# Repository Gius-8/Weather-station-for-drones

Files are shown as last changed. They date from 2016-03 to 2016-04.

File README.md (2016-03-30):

## Weather station for drones
The project consists of a kit for drones that includes an electronic device that functions as a meteorological station used for monitoring the values of environmental temperature, of atmospheric pressure and of humidity. The whole device'll work thanks to Arduino/Genuino MKR1000.
The electronic device will have inside a GPS locator so as to know the exact position of the analog readings of the different sensors.
The values acquired will be preserved in a KML files on a microSD and you can view them with Google Earth or Google Maps by simply importing the KML file.
They can be monitored in real time via Wi-Fi hotspot using a Smatphone, Tablet or PC.
In addition to the meteorological data, the device can acquire altitude, geographical coordinates and the speed of the drone in m/s.
The device consumes little power and can be powered by a 3.7V LiPo thanks to the potential of mkr1000 board.
In summary, the device will have the following characteristics:
You will be able to acquire:

- Temperature
- Atmospheric pressure
- Humidity
- Speed
- Altitude drone
- Geographic coordinates

Link tutorial: https://www.hackster.io/gius_8/weather-station-for-drones-1184cd

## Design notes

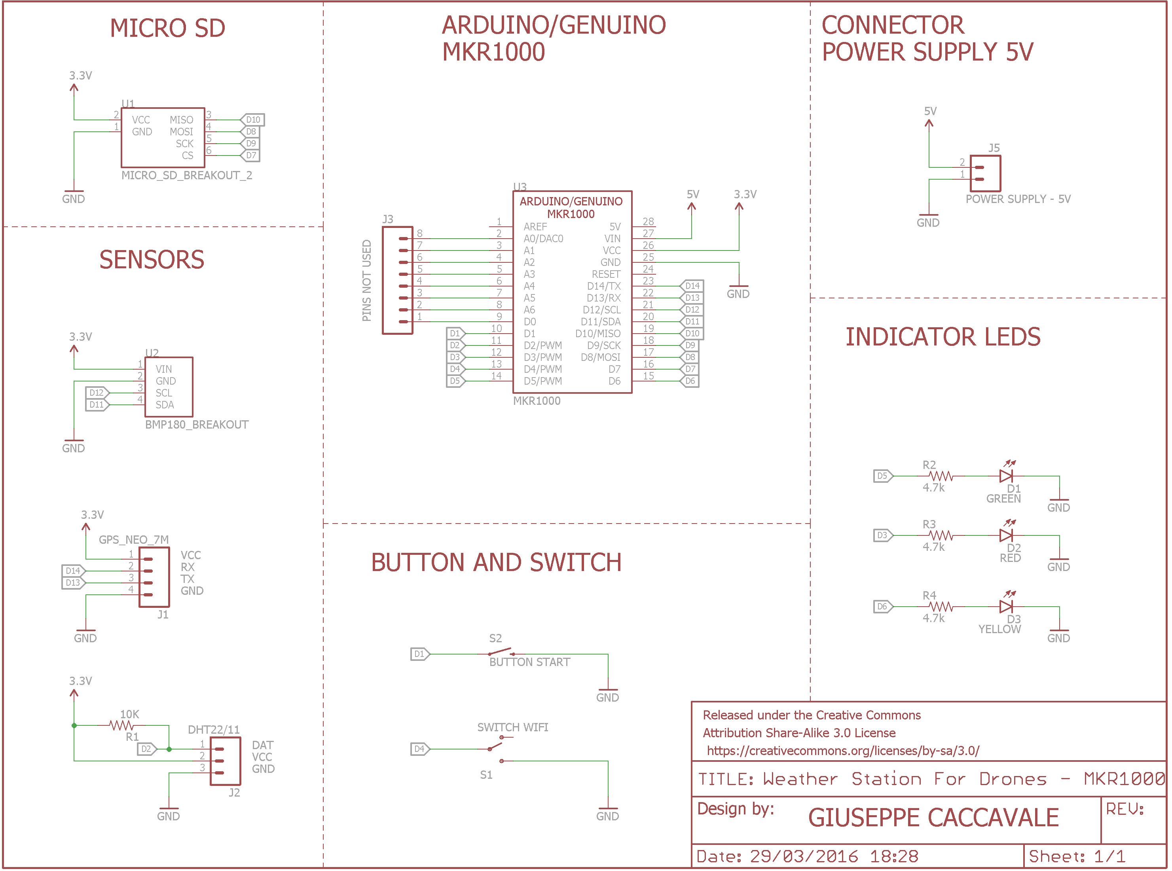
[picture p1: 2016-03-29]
Schematic_Weather_Station.png

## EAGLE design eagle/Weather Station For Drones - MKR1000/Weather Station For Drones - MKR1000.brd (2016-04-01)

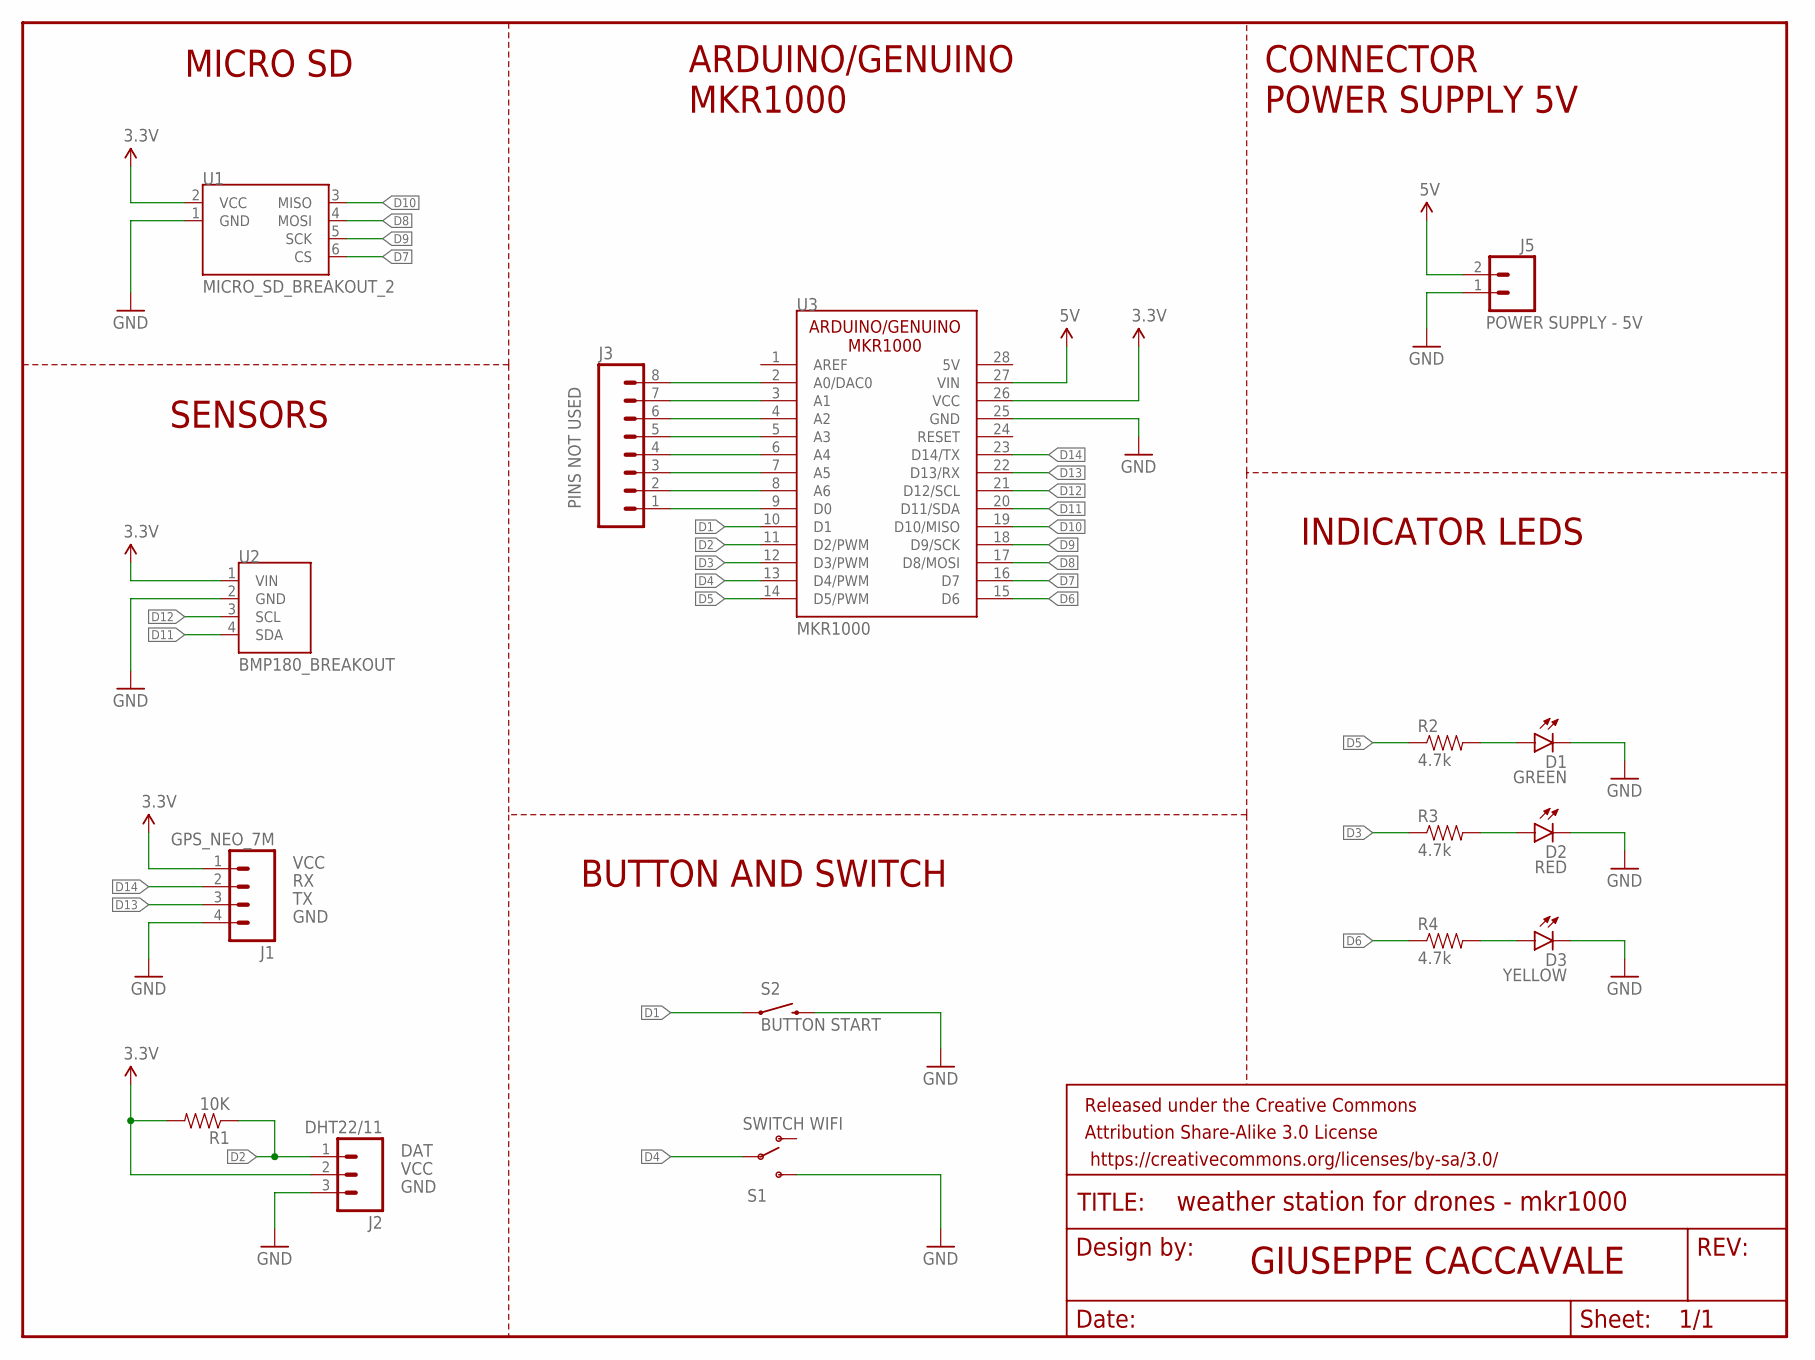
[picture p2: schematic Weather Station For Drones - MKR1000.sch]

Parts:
D1: GREEN; LED3MM
D2: RED; LED3MM
D3: YELLOW; LED3MM
FRAME1: FRAME-LETTER; CREATIVE_COMMONS
J1: GPS_NEO_7M; 1X04_LONGPADS
J2: DHT22/11; 1X03_LONGPADS
J3: PINS NOT USED; 1X08_LONGPADS
J5: POWER SUPPLY - 5V; JST-2-PTH
R1: 10K; AXIAL-0.3
R2, R3, R4: 4.7k; AXIAL-0.3
S1: SWITCH WIFI; SWITCH-SPDT_KIT
S2: BUTTON START; TACTILE-PTH
U1: MICRO_SD_BREAKOUT_2; MICRO_SD_ONLY_PIN
U2: BMP180_BREAKOUT
U3: MKR1000

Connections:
3.3V: J1.1, J2.2, R1.P$2 (2), U1.2 (VCC), U2.1 (VIN), U3.26 (VCC)
5V: J5.2, U3.27 (VIN)
D1: S2.1, S2.2 (1), U3.10 (D1)
D2: J2.1, R1.P$1 (1), U3.11 (D2/PWM)
D3: R3.P$1 (1), U3.12 (D3/PWM)
D4: S1.2, U3.13 (D4/PWM)
D5: R2.P$1 (1), U3.14 (D5/PWM)
D6: R4.P$1 (1), U3.15 (D6)
D7: U1.6 (CS), U3.16 (D7)
D8: U1.4 (MOSI), U3.17 (D8/MOSI)
D9: U1.5 (SCK), U3.18 (D9/SCK)
D10: U1.3 (MISO), U3.19 (D10/MISO)
D11: U2.4 (SDA), U3.20 (D11/SDA)
D12: U2.3 (SCL), U3.21 (D12/SCL)
D13: J1.3, U3.22 (D13/RX)
D14: J1.2, U3.23 (D14/TX)
GND: D1.K (C), D2.K (C), D3.K (C), J1.4, J2.3, J5.1, S1.3 (S), S2.3 (2), S2.4 (2), U1.1 (GND), U2.2 (GND), U3.25 (GND)
unnamed: D1.A, R2.P$2 (2)
unnamed: D2.A, R3.P$2 (2)
unnamed: J3.1, U3.9 (D0)
unnamed: J3.2, U3.8 (A6)
unnamed: J3.3, U3.7 (A5)
unnamed: J3.4, U3.6 (A4)
unnamed: J3.5, U3.5 (A3)
unnamed: J3.6, U3.4 (A2)
unnamed: J3.7, U3.3 (A1)
unnamed: J3.8, U3.2 (A0/DAC0)
unnamed: D3.A, R4.P$2 (2)

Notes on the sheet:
GND
VCC
DAT
GIUSEPPE CACCAVALE
SENSORS
CONNECTOR POWER SUPPLY 5V
INDICATOR LEDS
BUTTON AND SWITCH
ARDUINO/GENUINO MKR1000
MICRO SD

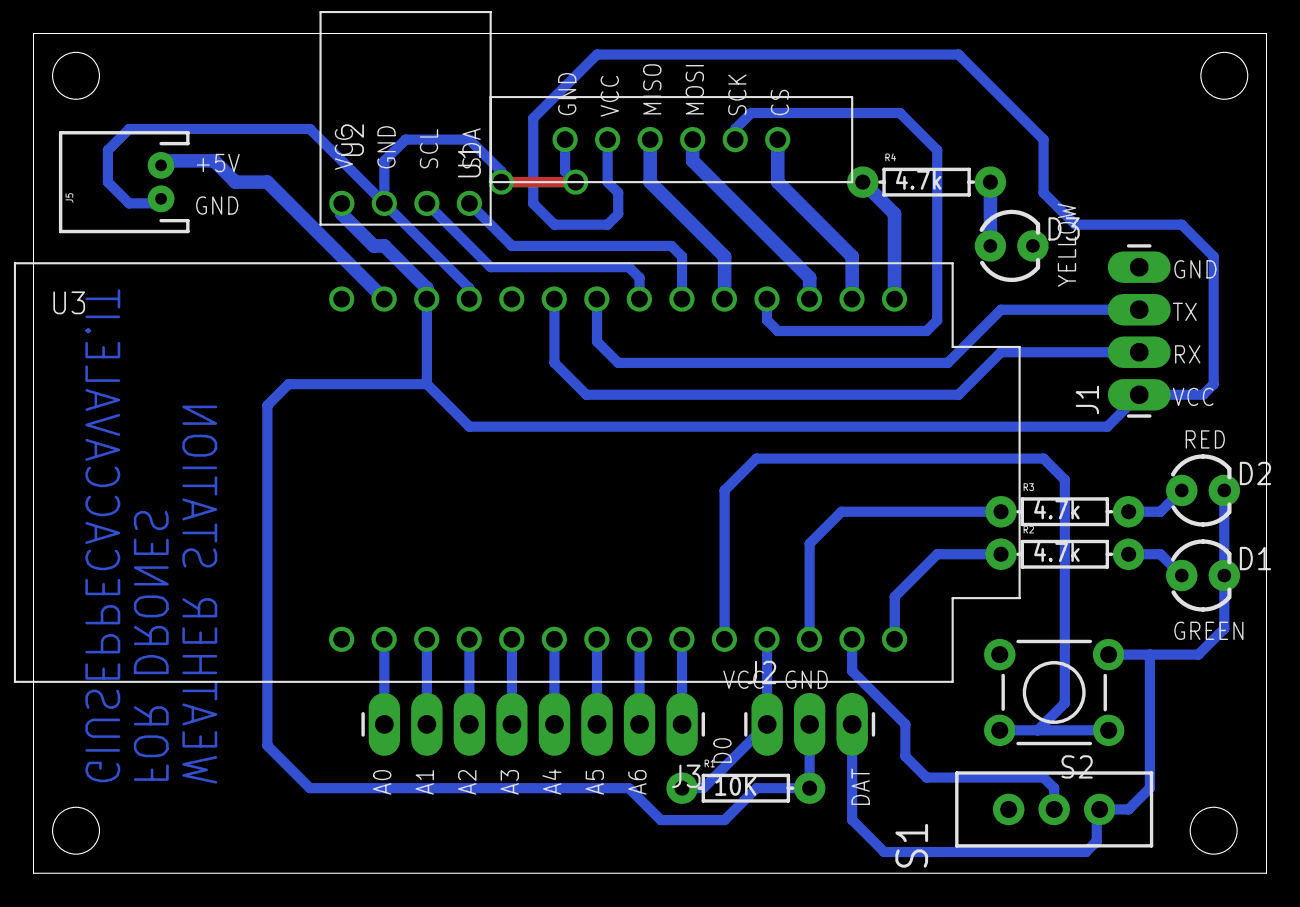
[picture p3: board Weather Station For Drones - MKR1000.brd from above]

Board: 2 copper layers, 73.6 x 50.2 mm, 17 parts (0 on the bottom side), 28 nets.

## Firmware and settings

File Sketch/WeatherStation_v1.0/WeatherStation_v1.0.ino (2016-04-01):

/*  WEATHER STATION FOR DRONES V1.0
    POWERED by GIUSEPPE CACCAVALE
    www.giuseppecaccavale.it

    Compatible with Arduino/Genuino MKR1000
    or Arduino Zero + Arduino Wifi Shield 101

    GitHub repository: https://github.com/Gius-8/Weather-station-for-drones

*/

#include <SPI.h>
#include <SD.h>
#include <Wire.h>
#include <Scheduler.h>
#include <SFE_BMP180.h>
#include <WiFi101.h>
#include <TinyGPS++.h>
#include "DHT.h"

// PIN used by MKR1000
#define PIN_SD 7
#define DHTPIN 2
const byte BUTTON_PIN = 1; //Start button
const byte SWITCH_WIFI = 4; //Switch wifi
const byte ledStart = 5;
const byte ledError = 3;
const byte ledGPS = 6;
/////////////////////////////////////////////

// Uncomment whatever type you're using!
//#define DHTTYPE DHT11   // DHT 11
#define DHTTYPE DHT22   // DHT 22  (AM2302), AM2321
//#define DHTTYPE DHT21   // DHT 21 (AM2301)

DHT dht(DHTPIN, DHTTYPE);

SFE_BMP180 pressure;

File myFile; //File .KML

static const uint32_t GPSBaud = 9600;
TinyGPSPlus gps; // The TinyGPS++ object

// Variables for debounce function
byte StateSwitch = 0;
int ButtPush;
int state = LOW;         // the current state of the output pin
int buttonState;             // the current reading from the input pin
int lastButtonState = HIGH;   // the previous reading from the input pin
long lastDebounceTime = 0;  // the last time the output pin was toggled
long debounceDelay = 50;    // the debounce time; increase if the output flickers

// Variables for Wifi function
char ssidAP[] = "WeatherStation"; // created AP name
int status = WL_IDLE_STATUS;
WiFiServer server(80);

// Variables for KML file
boolean WriteEncoding = false;
boolean WriteFolder = false;
boolean CreateFile = false;
int num = 0;
String file = "file";
String Combine = "";

// Variables in general
double lastLAT , lastLNG;
char Status;
double T, P, p0;
float t, h;
double lat, lng, speed, ALTITUDE;
int year;
byte month, day, hour, minute, second;
String DateString = "";
int i = 0;
boolean changeLocation = false;
boolean GPSstatus = false;

void setup() {

  file.reserve(10); //Reserve 10 byte for file
  Combine.reserve(20); //Reserve 20 byte for Combine
  DateString.reserve(30); //Reserve 60 byte for DateString

  pinMode(BUTTON_PIN, INPUT_PULLUP);
  pinMode(SWITCH_WIFI, INPUT_PULLUP);
  pinMode(ledStart, OUTPUT);
  pinMode(ledGPS, OUTPUT);
  pinMode(ledError, OUTPUT);
  digitalWrite(ledError, LOW);

  Scheduler.startLoop(loop1); // Initializes loop1

  Serial.begin(9600);
  Serial1.begin(GPSBaud);

  dht.begin(); // Initializes dht sensor
  pressure.begin(); // Initializes BMP180 sensor

  init_WifiAP(); // Initializes Wifi MKR1000

  if (!SD.begin(PIN_SD)) { // Initializes SD
    Serial.println("SD: initialization failed :(");
    digitalWrite(ledError, HIGH);
    while (true);
  }
  Serial.println("SD: initialization done :)");

}

void loop() {

  StateSwitch = digitalRead(SWITCH_WIFI);

  if (StateSwitch == LOW) {
    getBMP180data();
    getDHTdata();

    t = ((float)T + t) / 2;

    if (GPSstatus) {

      switch (ButtPush) {
        case LOW:
          writeKmlFile();
          break;
        case HIGH:
          if (CreateFile && WriteEncoding && WriteFolder) {

            close_myFile();
            reset_Variables();
            digitalWrite(ledStart, LOW); // led Status
            Serial.println("CLOSE SD.");
            Serial.println("STOP WRITING");
          }
          else {
            Serial.println("Press the button to start writing.");
          }
          break;
      }
    }
    else {
      Serial.println("GPS Signal Wait");
    }
    delay(5000);
  }
  else if (StateSwitch == HIGH) {
    getBMP180data();
    getDHTdata();

    t = ((float)T + t) / 2;

    if (CreateFile && WriteEncoding && WriteFolder) {
      close_myFile();
      reset_Variables();
      digitalWrite(ledStart, LOW); // led Status
      Serial.println("CLOSE SD.");
      Serial.println("STOP WRITING");
    }
    wifiLoop();
  }

}

void loop1() {
  if(StateSwitch == LOW) ButtPush = debounce(BUTTON_PIN);

 /* if (ButtPush == HIGH && GPSstatus && StateSwitch == LOW)
    digitalWrite(ledStart, LOW);
  else if (ButtPush == LOW && GPSstatus && StateSwitch == LOW)
    digitalWrite(ledStart, HIGH);*/

  while (Serial1.available() > 0)
    if (gps.encode(Serial1.read()))
      getGPSdata();

  if (GPSstatus)
    digitalWrite(ledGPS, HIGH);
  else
    digitalWrite(ledGPS, LOW);

  if (millis() > 5000 && gps.charsProcessed() < 10) {
    Serial.println(F("No GPS detected: check wiring."));
    digitalWrite(ledError, HIGH);
    while (true);
  }

  yield();
}

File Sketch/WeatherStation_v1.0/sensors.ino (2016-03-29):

//Functions DHT
void getDHTdata() {

  if (isnan(h) || isnan(t)) {
    Serial.println("Failed to read from DHT sensor!");
    digitalWrite(ledError, HIGH);
    while(true);
  }

  h = dht.readHumidity();
  t = dht.readTemperature();
}

void getBMP180data() {
  Status = pressure.startTemperature();
  if (Status != 0)
  {
    // Wait for the measurement to complete:
    delay(Status);

    // Retrieve the completed temperature measurement:
    // Note that the measurement is stored in the variable T.
    // Function returns 1 if successful, 0 if failure.

    Status = pressure.getTemperature(T);
    if (Status != 0)
    {
      // Start a pressure measurement:
      // The parameter is the oversampling setting, from 0 to 3 (highest res, longest wait).
      // If request is successful, the number of ms to wait is returned.
      // If request is unsuccessful, 0 is returned.

      Status = pressure.startPressure(3);
      if (Status != 0)
      {
        // Wait for the measurement to complete:
        delay(Status);

        // Retrieve the completed pressure measurement:
        // Note that the measurement is stored in the variable P.
        // Note also that the function requires the previous temperature measurement (T).
        // (If temperature is stable, you can do one temperature measurement for a number of pressure measurements.)
        // Function returns 1 if successful, 0 if failure.

        Status = pressure.getPressure(P, T);
        if (Status != 0)
        {
          // The pressure sensor returns abolute pressure, which varies with altitude.
          // To remove the effects of altitude, use the sealevel function and your current altitude.
          // This number is commonly used in weather reports.
          // Parameters: P = absolute pressure in mb, ALTITUDE = current altitude in m.
          // Result: p0 = sea-level compensated pressure in mb

          p0 = pressure.sealevel(P, ALTITUDE);
        }
        else Serial.println("BMP180: error retrieving pressure measurement\n");
      }
      else Serial.println("BMP180: error starting pressure measurement\n");
    }
    else Serial.println("BMP180: error retrieving temperature measurement\n");
  }
  else Serial.println("BMP180: error starting temperature measurement\n");
}

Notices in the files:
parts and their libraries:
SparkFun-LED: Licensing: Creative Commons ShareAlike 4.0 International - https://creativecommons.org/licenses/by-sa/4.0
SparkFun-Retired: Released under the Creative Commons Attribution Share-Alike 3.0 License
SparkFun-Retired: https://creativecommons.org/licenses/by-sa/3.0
